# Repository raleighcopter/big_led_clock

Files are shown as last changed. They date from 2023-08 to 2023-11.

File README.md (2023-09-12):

BFC 1.0 (Big Filament Clock 1.0)

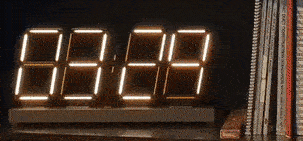
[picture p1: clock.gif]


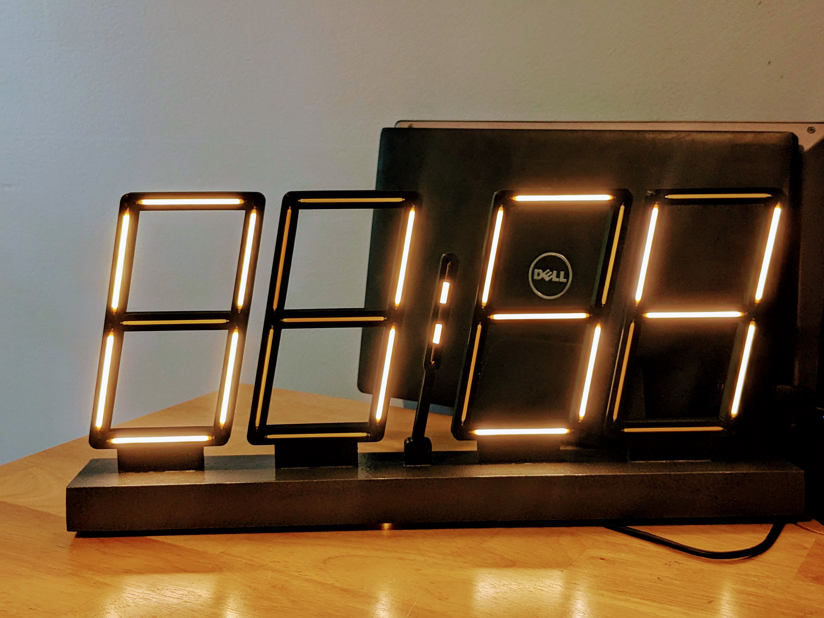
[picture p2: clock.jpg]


Some notes...

this clock is 17" x8" x 2.5" overall.

uses 68mm 3v filaments sourced from aliexpress. digits are about 6.5" tall. get the gps module and bme280 sensor for the optional transmitter there too.

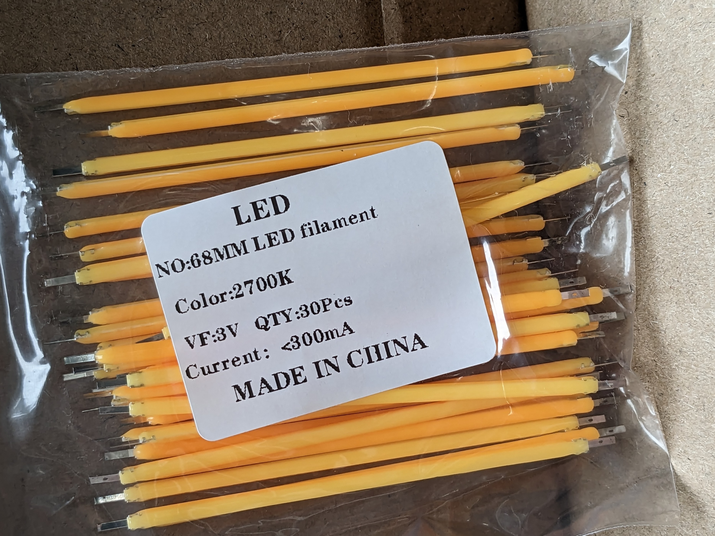
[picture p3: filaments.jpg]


the clock software now has the ability to blank leading zeros and the ability to display in 12 or 24 hour format through a few configuration settings.

the clock has the option to add a couple transistors (ss8550 with 1k base resistor) and configure the software to dim the entire display during night hours or without the addition of 2 transistors, to dim the colon and turn the digits off. You can optionally omit the buck converter but it does add some display brightness control, especially if you omit the ss8550 transistors which can dim the digits with a bit of code configuration changes.

Order extra LED filaments. They're brittle, fragile and you will break more than one. Sourced from AliExpress. the digits are wired common anode (the white wire).
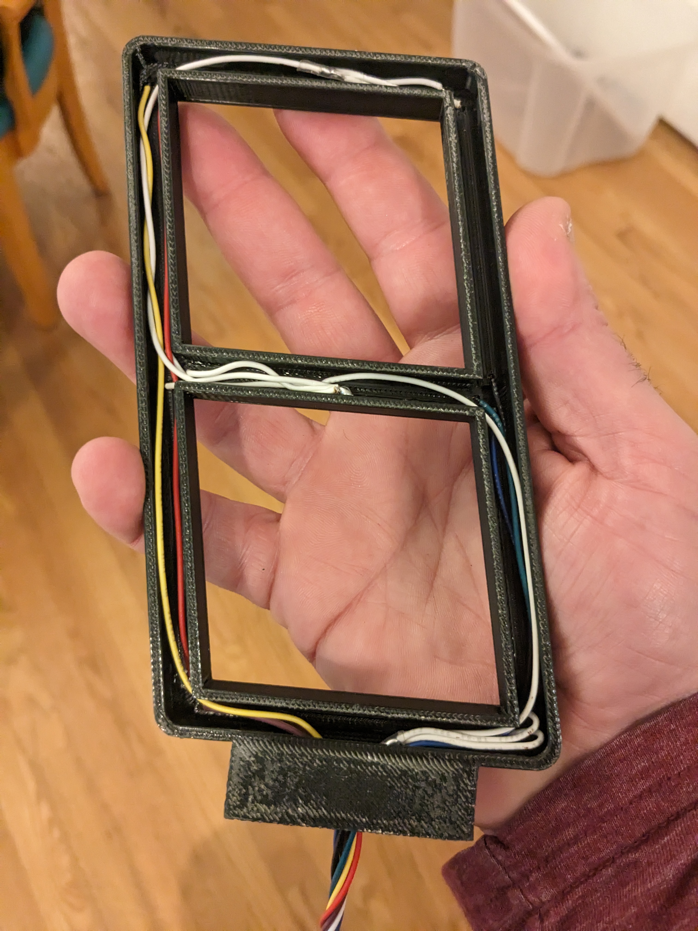
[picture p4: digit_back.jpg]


Here's a picture of the front.
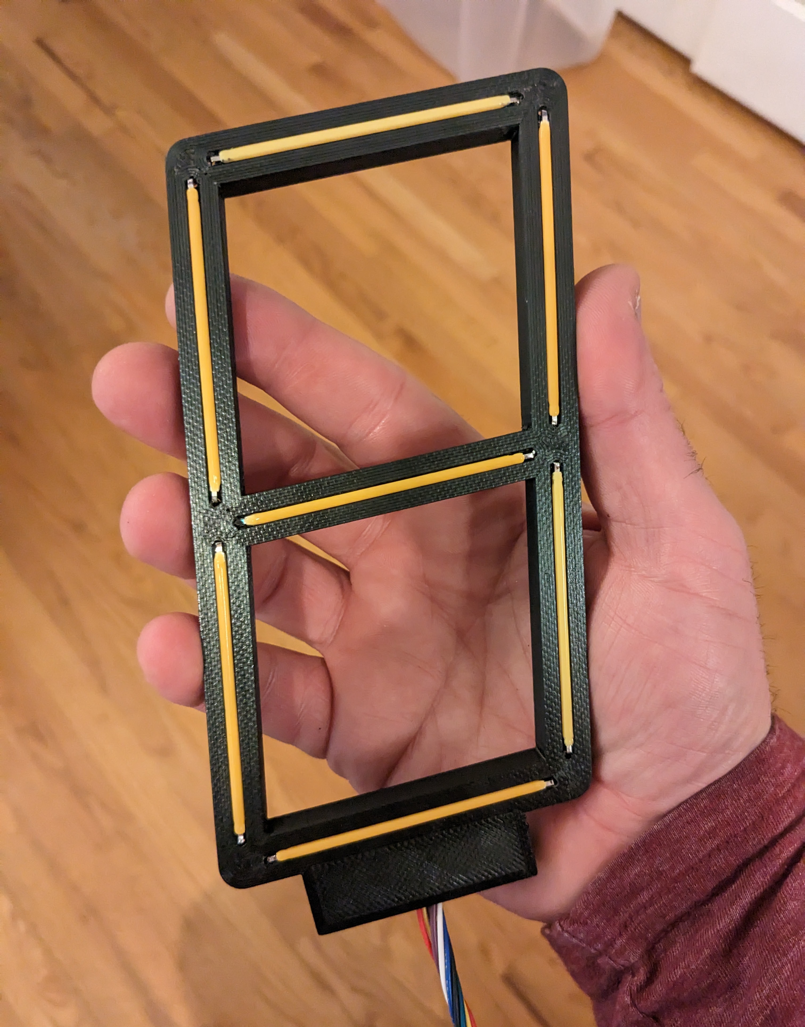
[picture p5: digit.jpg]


THE 433 MHZ receiver/transmitter with functionality is also working and an optional transmitter with bme280 (recommended) or si7021 temp/rh sensor can be used to wirelessly transmit weather data to the clock. you can build the clock with the receiver and build the transmitter at a later date and the clock will only display time unless a transmitter with matching transmitter code is detected.

The 3v converter can be omitted but you won't be able to set the brightness of the LEDs if you do, so play with the value of the series resistors for the LEDs if you omit the buck converter. You want at least 100 ohm series resistors, possibly higher.
  
You can omit the DST switch and just use the hour offset pot to adjust the hour for DST.

I used 1/4" poplar for the base and painted it with some left-over hammer tone grey paint i had on hand.

I used 3er perf board to build the circuit. It's available cheapest on eBay.

The GPS module is a neo6m module from AliExpress and it provides an accurate time source. more importantly, after a power outage, the clock will come back with the correct time without the need to set the clock and it doesn't require a battery backup, just a weak gps signal.

Drill the holes for the filament wires out to about 3/64" so the filaments don't break when installing them.they should be just big enough to get the wire and solder through but not too big or the filament won't stay in place. the LEDs are very fragile and you will break a few.

Use 1/8" black heat shrink to make the single filament in the colon look like a colon.

Wire the entire thing with 26 gage stranded. Get an assortment of colors to help stay organized. 8 colors or more is best.

here's a photo of the clock wiring.

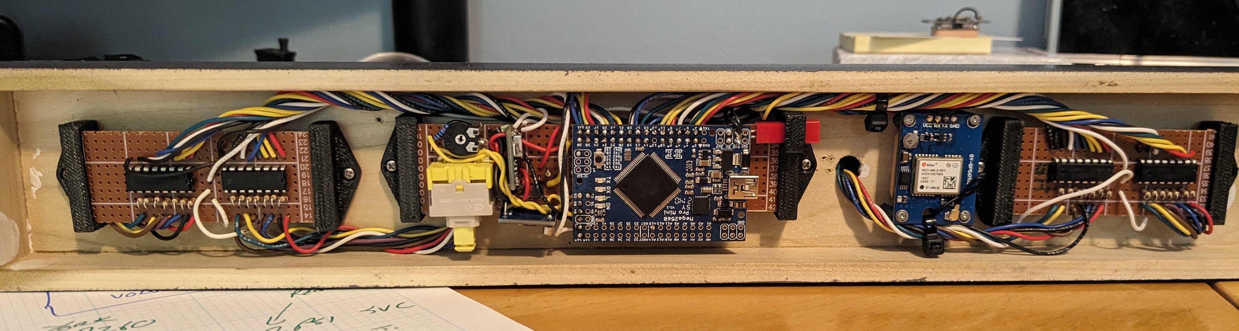
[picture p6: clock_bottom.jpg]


here's a photo of the transmitter built on a pro-mini with bme280 sensor and 433MHz transmitter. it can be built using the BME280 or the si7021 sensor. firmware for each is provided. i didn't do a schematic for the transmitter because its fairly trivial. the sensors are i2c and the transmitter pin is listed in the source code. the si7021 doesn't do well with relative humidity above 80% for extended periods which is daily around here so i use the BME280. 

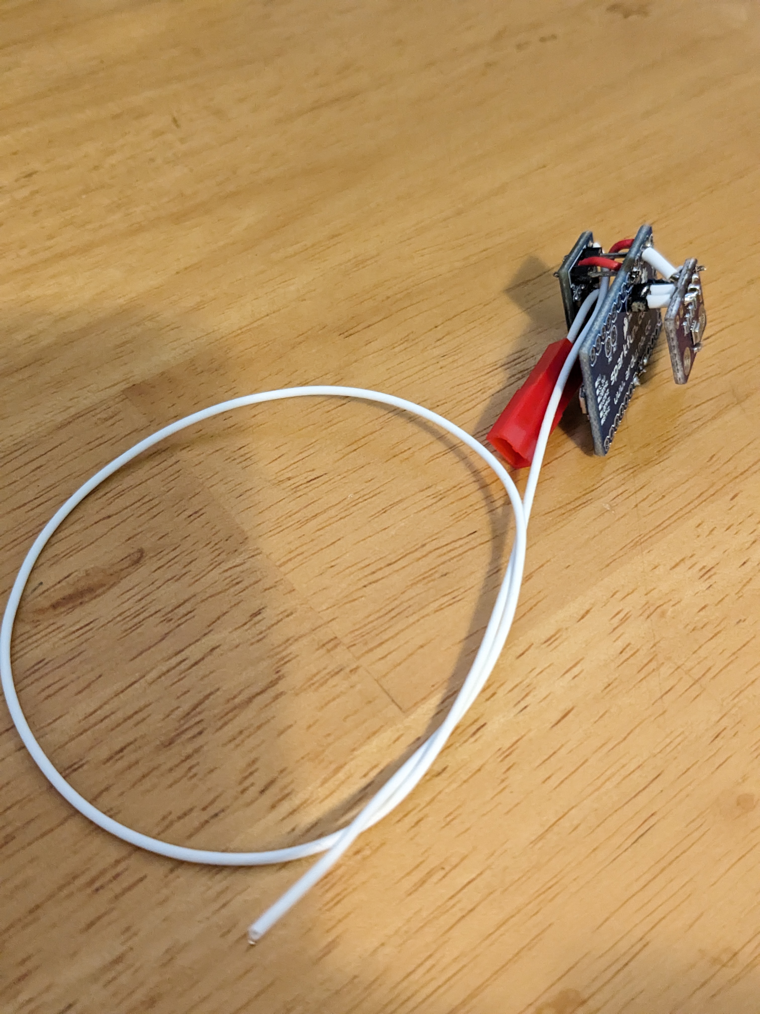
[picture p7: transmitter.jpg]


and the transmitter in the gill screen(top off).

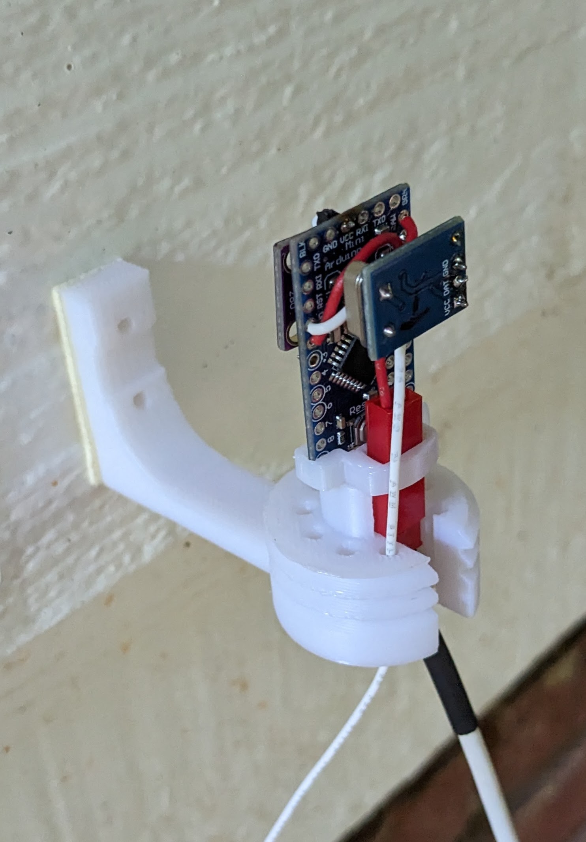
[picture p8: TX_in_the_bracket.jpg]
.

Contact me at d.a.taylor.pe@gmail.com

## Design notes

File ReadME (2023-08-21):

Big Clock

Some notes...

Order extra LED filaments. They're brittle, fragile and you will break more than one. Sourced from AliExpress.

THE 433 MHZ functionality is not incorporated yet.

The 3v converter can be omitted but you won't be able to set the brightness of the LEDs if you do so play with the value of the series resistors for the LEDs. You want at least 100 ohm series resistors, possibly higher.
  
You can omit the DST switch and just use the hour offset pot to adjust the hour for DST.

I used 1/4" poplar for the base and painted it with some hammer tone grey paint.

I used 3er perf board to build the circuit. It's available cheapest on eBay.

The GPS module is a neo6m module from AliExpress.

Drill the holes for the filament wires out to about 3/64" so the filaments don't break when installing them.they should be just big enough to get the wire and solder through but not too big or the filament won't stay in place.

Use heat shrink to make the single filament in the colon look like a colon.

Wire the entire thing with 22 gage stranded. Get an assortment of colors to help stay organized. 8 colors or more is best.

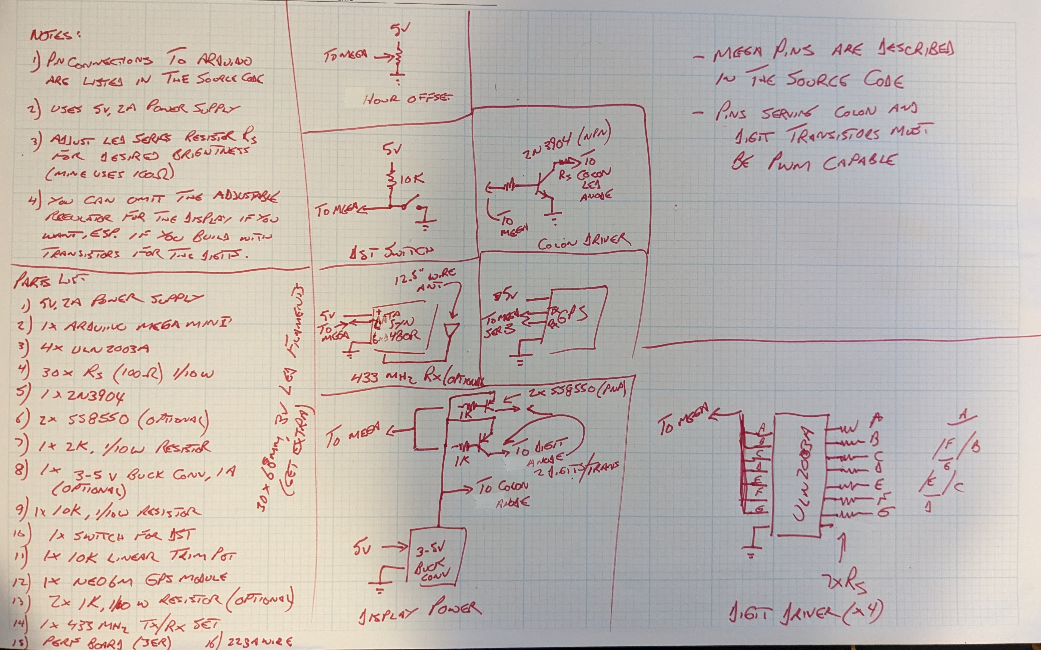
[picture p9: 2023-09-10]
clock_schematic.jpg

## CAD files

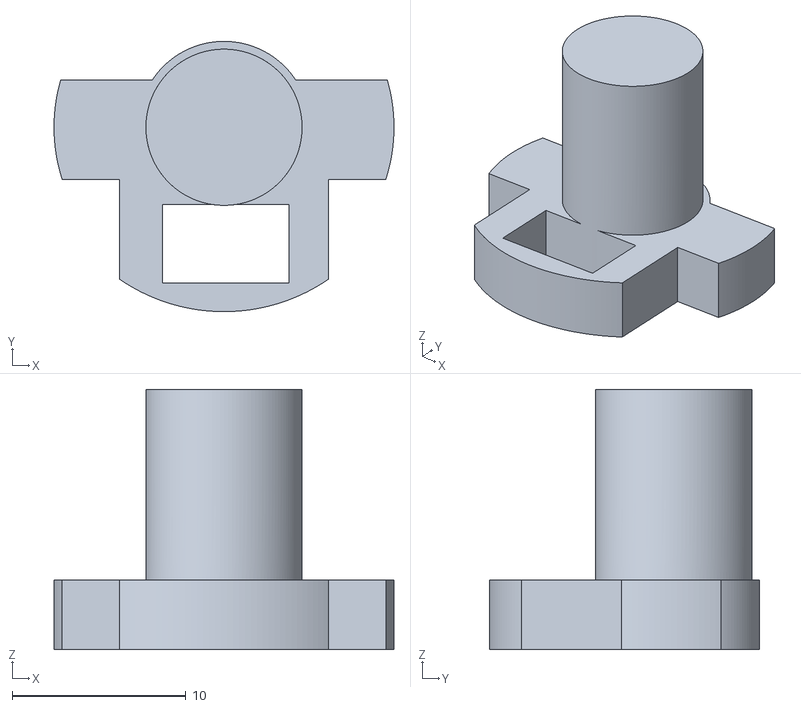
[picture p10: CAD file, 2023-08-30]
transmitter bracket.stl
19.6 x 15.6 x 15.0

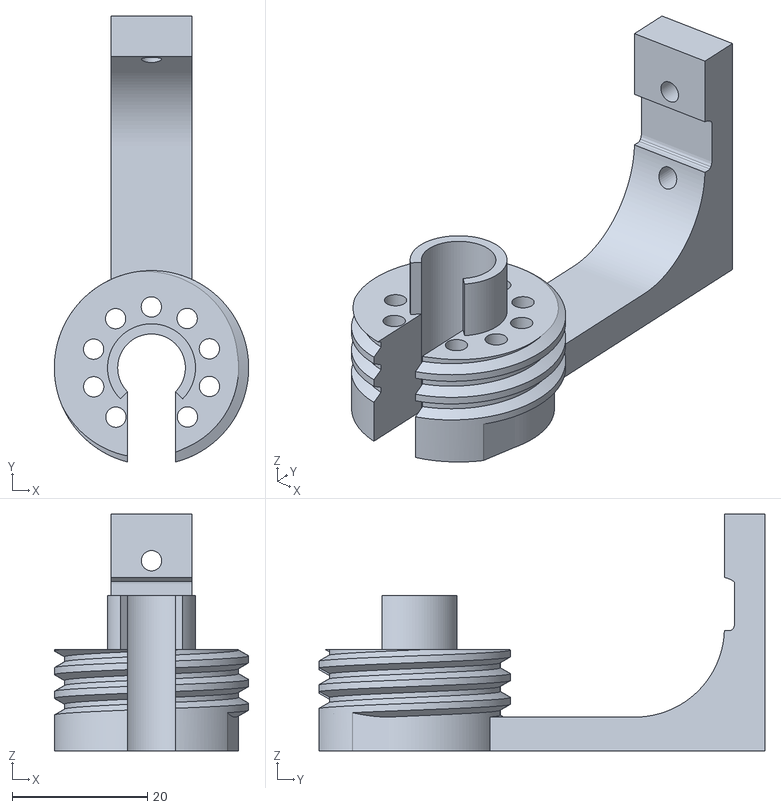
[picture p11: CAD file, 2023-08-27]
stevenson_base.stl
28.7 x 65.9 x 35.0

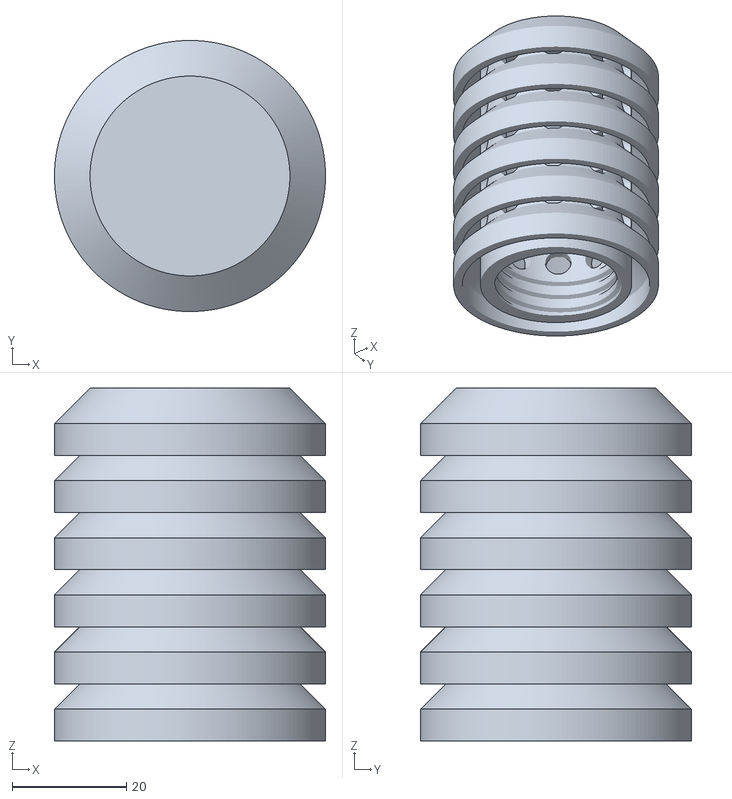
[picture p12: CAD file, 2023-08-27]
stevenson_cap.stl
47.5 x 47.5 x 61.8

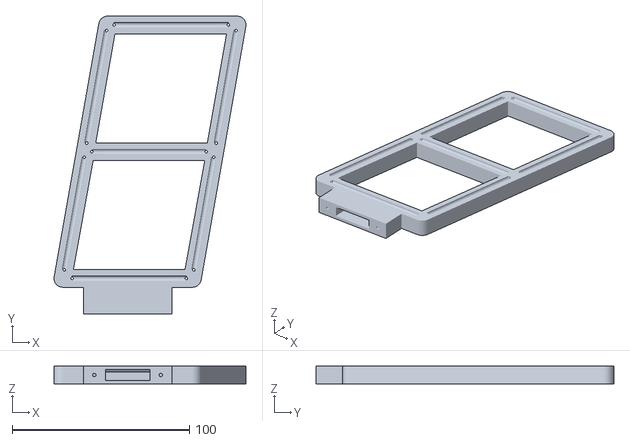
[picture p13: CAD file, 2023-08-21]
number.stl
108.4 x 168.1 x 10.0

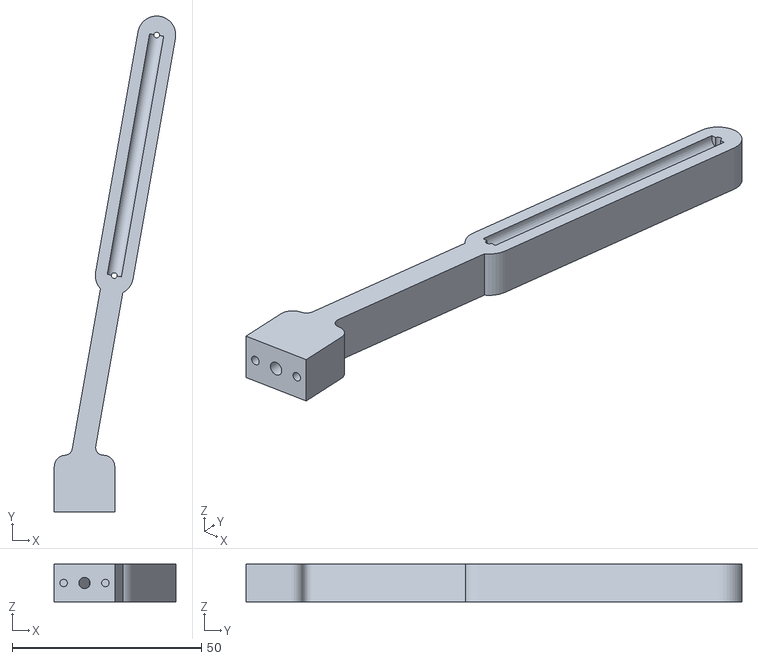
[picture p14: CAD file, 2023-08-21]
colon.stl
32.1 x 131.0 x 10.0

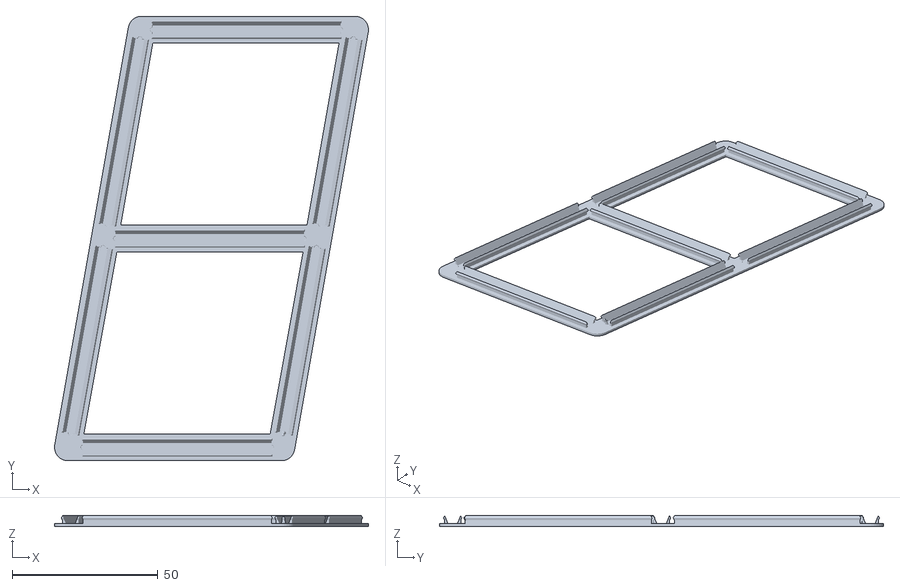
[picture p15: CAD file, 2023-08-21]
Back.stl
107.6 x 152.3 x 3.80

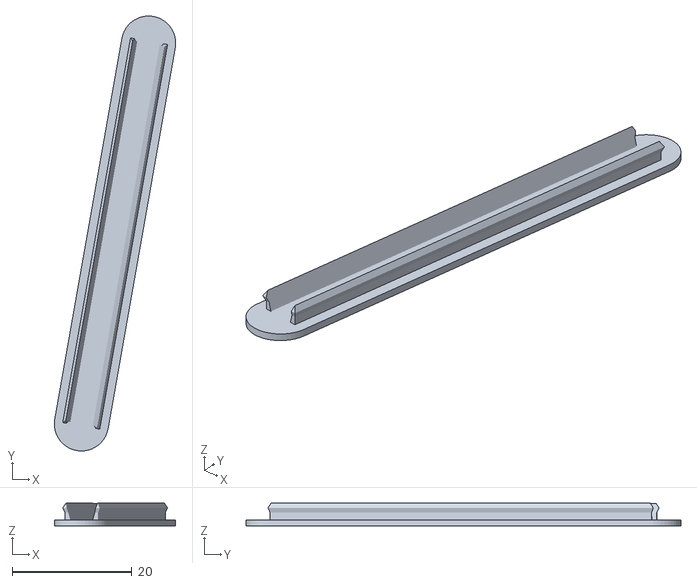
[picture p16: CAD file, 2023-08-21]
colon back.stl
20.3 x 72.6 x 3.80

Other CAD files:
clock digits.f3d
transmitter bracket.f3d

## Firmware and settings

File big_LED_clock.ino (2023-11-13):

/*


the segments of the digits are labeled as follows
         _____    
        /  A /   
       /F   /B  
      /____/     
     /  G /    
    /E   /C  
   /____/     
     D           

the gps is wired to serial3 (14,15)

*/


//make config changes in the area of code below

int leading_zero_blanking = 1; //set to 1 to enable
int format_12 = 1; //set to 1 to enable 12 hour time
int receiver_code = 152; //must match transmitter code
int dimmable_display = 1; //set to 1 if the display is wired with a PNP transistor (ss8550 with 1k base resistor) on the display power wire
int nite_off = 23; // dim display at this hour and after
int morning_on = 7; // dim display before this hour
int dim_level = 5; //amount to dim display (0-255)
int display_dim_pin = 44; //optional pwm pin for display digit dimming
int offset_pin = A15; //analog pin for hour offset pot
int dst_pin = 48; //the dst button pin
int RF_data_pin = 40; //the receiver data pin

//pins that the display segments are wired to are defined below

int hours_ten_a = 27;
int hours_ten_b = 28;
int hours_ten_c = 29;
int hours_ten_d = 30;
int hours_ten_e = 31;
int hours_ten_f = 46;
int hours_ten_g = 47;

int hours_one_a = 20;
int hours_one_b = 21;
int hours_one_c = 22;
int hours_one_d = 23;
int hours_one_e = 24;
int hours_one_f = 25;
int hours_one_g = 26;

int minutes_ten_a = 9;
int minutes_ten_b = 10;
int minutes_ten_c = 11;
int minutes_ten_d = 16;
int minutes_ten_e = 17;
int minutes_ten_f = 18;
int minutes_ten_g = 19;

int minutes_one_a = 2;
int minutes_one_b = 7;
int minutes_one_c = 6;
int minutes_one_d = 5;
int minutes_one_e = 4;
int minutes_one_f = 3;
int minutes_one_g = 8;

int colon = 13; // the pin that the colon is wired to. must be a PWM capable pin

// make config changes above this line only

#include <TinyGPS++.h>  //TinyGPSPlus library
#include <RH_ASK.h>     //Radiohead library

RH_ASK driver(2000, RF_data_pin, 0, 0);

static const uint32_t GPSBaud = 9600;

int on = 1;
int off = 0;
int dot_count;
int colon_val;
int hi_dot = 255;

int hour_offset;

int a;
int b;
int c;
int d;
int e;
int f;
int g;

int hours = 0;
int minutes = 0;
int seconds = 0;
int hours_ten = 0;
int hours_one = 0;
int minutes_ten = 0;
int minutes_one = 0;

int weather_time = 0;
int weather_valid = 0;
int Temp;
int RH;

TinyGPSPlus gps;

void setup()
{

#ifdef RH_HAVE_SERIAL
    Serial.begin(9600);	  // Debugging only
#endif
    if (!driver.init())
#ifdef RH_HAVE_SERIAL
         Serial.println("init failed");
#else
         Serial.println("init success");	;
#endif

  Serial3.begin(GPSBaud);

  pinMode(hours_ten_a, OUTPUT);
  pinMode(hours_ten_b, OUTPUT);
  pinMode(hours_ten_c, OUTPUT);
  pinMode(hours_ten_d, OUTPUT);
  pinMode(hours_ten_e, OUTPUT);
  pinMode(hours_ten_f, OUTPUT);
  pinMode(hours_ten_g, OUTPUT);
  pinMode(hours_one_a, OUTPUT);
  pinMode(hours_one_b, OUTPUT);
  pinMode(hours_one_c, OUTPUT);
  pinMode(hours_one_d, OUTPUT);
  pinMode(hours_one_e, OUTPUT);
  pinMode(hours_one_f, OUTPUT);
  pinMode(hours_one_g, OUTPUT);
  pinMode(minutes_ten_a, OUTPUT);
  pinMode(minutes_ten_b, OUTPUT);
  pinMode(minutes_ten_c, OUTPUT);
  pinMode(minutes_ten_d, OUTPUT);
  pinMode(minutes_ten_e, OUTPUT);
  pinMode(minutes_ten_f, OUTPUT); 
  pinMode(minutes_ten_g, OUTPUT);
  pinMode(minutes_one_a, OUTPUT);
  pinMode(minutes_one_b, OUTPUT);
  pinMode(minutes_one_c, OUTPUT);
  pinMode(minutes_one_d, OUTPUT);
  pinMode(minutes_one_e, OUTPUT);
  pinMode(minutes_one_f, OUTPUT);
  pinMode(minutes_one_g, OUTPUT);
  pinMode(dst_pin, INPUT); 
}

void loop()
{
//get weather data if available
  int data[3] = {0};
      uint8_t buflen = sizeof(data);
    if (driver.recv((uint8_t*)data, &buflen));
   {
  if (data[0] == receiver_code) {  //throw away bad data
    RH = data[1];
    Temp = data[2];
    weather_time =  (60 * minutes) + seconds; //record time of weather aquisition
    weather_valid = 1; //mark weather as valid
  }
}


  // This sketch displays information every time a new NMEA sentence is correctly encoded.
  while (Serial3.available() > 0)
    if (gps.encode(Serial3.read()))
      displayInfo();

  if (millis() > 5000 && gps.charsProcessed() < 10)
  {
    Serial.println(F("No GPS detected: check wiring."));
    while(true);
  }
  hour_offset = map(analogRead(offset_pin), 0, 1023, 23, 0) + digitalRead(dst_pin);

}

void displayInfo()
{
  if (gps.time.isValid())
// store values in working variables 
  {
  hours = gps.time.hour();
  minutes = gps.time.minute();
  seconds = gps.time.second();

  hours = hours + hour_offset;



//invalidate weather data that's too old
if ((60 * minutes + seconds) - weather_time >= 60) {
  weather_valid = 0;
}

//adjust to 24 hour local time
  if (hours > 24) hours = hours - 24;
  if (hours < 1) hours = hours + 24;

// dim during off hours
    if ((hours >= nite_off) or (hours < morning_on)) {
      hi_dot = dim_level; //dim the colon
      if (dimmable_display == 1) { //dim the digits if they're dimmable
        analogWrite(display_dim_pin, (255 - dim_level));
      }
      else {
        on = 0; //digits not dimmable so turn them off
      }
    } else {
      hi_dot = 255;
      on = 1;
      analogWrite(display_dim_pin, 0);
    }

//ramp up during morning_on hour


//ramp down during nite_off hour


//convert to 12 hour format if format_12 = 1  
  if (format_12 == 1) {
    if (hours > 12) hours = hours - 12;
    if (hours < 1) hours = hours + 12;
    }
   }


//determine if we should display time or temp
if ((weather_valid == 1) and seconds % 10 >= 8) {
//display RH
    colon_val = off;
    hours_ten = (RH/10);
    hours_one = (RH - (10 * hours_ten));
    minutes_ten = 11;
    minutes_one = 12;
}

if ((weather_valid == 1) and (seconds % 10 >= 6 and seconds %10 < 8) ) {
  colon_val = off;
//display temp
  if ((Temp < 0) and (Temp >= -9)) {
    Temp = abs(Temp);
    hours_ten = 10;  // minus
    hours_one = Temp;
    minutes_ten = 10; //degrees
    minutes_one = 11; //F
  } else if (Temp <= -10) {
    Temp = abs(Temp);
    hours_ten = 10; //minus
    hours_one = (Temp/10);
    minutes_ten = (Temp - (10 * hours_one));
    minutes_one = 10; //degrees
  } else if ((Temp >= 0) and (Temp <100)) {
    hours_ten = (Temp/10);
    hours_one = (Temp - (10 * hours_ten));
    minutes_ten = 10; //degrees
    minutes_one = 11; //F
  } else if (Temp >= 100) {
    hours_ten = 1;
    Temp = Temp - 100;
    hours_one = (Temp/10);
    minutes_ten = (Temp - (10 * hours_one));
    minutes_one = 10; //degrees     
    }
}

if ((seconds % 10 <= 5) or (weather_valid == 0)) {
//display time
// calculate values for separate digits to display time
  hours_ten = (hours/10);
  hours_one = (hours - (10 * hours_ten));
  minutes_ten = (minutes/10);
  minutes_one = (minutes - (10 * minutes_ten));

//do colon stuff....
  dot_count = seconds % 2;

  switch(dot_count)
  {
    case 0: colon_val = hi_dot; break;
    case 1: colon_val = off; break; 
  }
}


//do display stuff
// write colon

analogWrite(colon, colon_val);

// set the display segments

switch(hours_ten)
{
  case 0: if (leading_zero_blanking = 0) {
    a=on;b=on;c=on;d=on;e=on;f=on;g=off;
    } else { 
    a=off;b=off;c=off;d=off;e=off;f=off;g=off;
    }
    break;
  case 1: a=off;b=on;c=on;d=off;e=off;f=off;g=off;break;
  case 2: a=on;b=on;c=off;d=on;e=on;f=off;g=on;break;
  case 3: a=on;b=on;c=on;d=on;e=off;f=off;g=on;break;
  case 4: a=off;b=on;c=on;d=off;e=off;f=on;g=on;break;
  case 5: a=on;b=off;c=on;d=on;e=off;f=on;g=on;break;
  case 6: a=on;b=off;c=on;d=on;e=on;f=on;g=on;break;
  case 7: a=on;b=on;c=on;d=off;e=off;f=off;g=off;break;
  case 8: a=on;b=on;c=on;d=on;e=on;f=on;g=on;break;
  case 9: a=on;b=on;c=on;d=off;e=off;f=on;g=on;break;
  case 10: a=off;b=off;c=off;d=off;e=off;f=off;g=on;break; // - symbol    
}
// write hours_ten digit display pins
  
digitalWrite(hours_ten_a, a);
digitalWrite(hours_ten_b, b);
digitalWrite(hours_ten_c, c);
digitalWrite(hours_ten_d, d);
digitalWrite(hours_ten_e, e);
digitalWrite(hours_ten_f, f);
digitalWrite(hours_ten_g, g);

switch(hours_one)
{
  case 0: a=on;b=on;c=on;d=on;e=on;f=on;g=off;break;
  case 1: a=off;b=on;c=on;d=off;e=off;f=off;g=off;break;
  case 2: a=on;b=on;c=off;d=on;e=on;f=off;g=on;break;
  case 3: a=on;b=on;c=on;d=on;e=off;f=off;g=on;break;
  case 4: a=off;b=on;c=on;d=off;e=off;f=on;g=on;break;
  case 5: a=on;b=off;c=on;d=on;e=off;f=on;g=on;break;
  case 6: a=on;b=off;c=on;d=on;e=on;f=on;g=on;break;
  case 7: a=on;b=on;c=on;d=off;e=off;f=off;g=off;break;
  case 8: a=on;b=on;c=on;d=on;e=on;f=on;g=on;break;
  case 9: a=on;b=on;c=on;d=off;e=off;f=on;g=on;break;           
}
// write hours_one digit display pins
  
digitalWrite(hours_one_a, a);
digitalWrite(hours_one_b, b);
digitalWrite(hours_one_c, c);
digitalWrite(hours_one_d, d);
digitalWrite(hours_one_e, e);
digitalWrite(hours_one_f, f);
digitalWrite(hours_one_g, g);

switch(minutes_ten)
{
  case 0: a=on;b=on;c=on;d=on;e=on;f=on;g=off;break;
  case 1: a=off;b=on;c=on;d=off;e=off;f=off;g=off;break;
  case 2: a=on;b=on;c=off;d=on;e=on;f=off;g=on;break;
  case 3: a=on;b=on;c=on;d=on;e=off;f=off;g=on;break;
  case 4: a=off;b=on;c=on;d=off;e=off;f=on;g=on;break;
  case 5: a=on;b=off;c=on;d=on;e=off;f=on;g=on;break;
  case 6: a=on;b=off;c=on;d=on;e=on;f=on;g=on;break;
  case 7: a=on;b=on;c=on;d=off;e=off;f=off;g=off;break;
  case 8: a=on;b=on;c=on;d=on;e=on;f=on;g=on;break;
  case 9: a=on;b=on;c=on;d=off;e=off;f=on;g=on;break;
  case 10: a=on;b=on;c=off;d=off;e=off;f=on;g=on;break; // degree symbol
  case 11: a=off;b=off;c=off;d=off;e=on;f=off;g=on;break; //r      
}
// write minutes_ten digit display pins
  
digitalWrite(minutes_ten_a, a);
digitalWrite(minutes_ten_b, b);
digitalWrite(minutes_ten_c, c);
digitalWrite(minutes_ten_d, d);
digitalWrite(minutes_ten_e, e);
digitalWrite(minutes_ten_f, f);
digitalWrite(minutes_ten_g, g);

switch(minutes_one)
{
  case 0: a=on;b=on;c=on;d=on;e=on;f=on;g=off;break;
  case 1: a=off;b=on;c=on;d=off;e=off;f=off;g=off;break;
  case 2: a=on;b=on;c=off;d=on;e=on;f=off;g=on;break;
  case 3: a=on;b=on;c=on;d=on;e=off;f=off;g=on;break;
  case 4: a=off;b=on;c=on;d=off;e=off;f=on;g=on;break;
  case 5: a=on;b=off;c=on;d=on;e=off;f=on;g=on;break;
  case 6: a=on;b=off;c=on;d=on;e=on;f=on;g=on;break;
  case 7: a=on;b=on;c=on;d=off;e=off;f=off;g=off;break;
  case 8: a=on;b=on;c=on;d=on;e=on;f=on;g=on;break;
  case 9: a=on;b=on;c=on;d=off;e=off;f=on;g=on;break;
  case 10: a=on;b=on;c=off;d=off;e=off;f=on;g=on;break; // degree symbol
  case 11: a=on;b=off;c=off;d=off;e=on;f=on;g=on;break; // F
  case 12: a=off;b=off;c=on;d=off;e=on;f=on;g=on;break; //h           
}
// write minutes_one digit display pins
  
digitalWrite(minutes_one_a, a);
digitalWrite(minutes_one_b, b);
digitalWrite(minutes_one_c, c);
digitalWrite(minutes_one_d, d);
digitalWrite(minutes_one_e, e);
digitalWrite(minutes_one_f, f);
digitalWrite(minutes_one_g, g);
  
}

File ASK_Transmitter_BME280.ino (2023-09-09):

//transmits temp and relative humidity data. 
//build on arduino nano or pro mini.
//uses an bme280 sensor and cheap 433 MHz transmitter.
//the transmitter connects to D2. 
//sends a new set of data about every 3 seconds.

#include <RH_ASK.h>
#ifdef RH_HAVE_HARDWARE_SPI
#include <SPI.h> 
#include <Wire.h>
#include <Adafruit_Sensor.h>
#include <Adafruit_BME280.h>
#endif
Adafruit_BME280 bme; // I2C

RH_ASK driver(2000, 0, 2, 0);

int transmitter_code = 152; // must match receiver code
void setup()
{
unsigned status;

status = bme.begin(0x76);

#ifdef RH_HAVE_SERIAL
    Serial.begin(9600);	  // Debugging only
#endif
    if (!driver.init())
#ifdef RH_HAVE_SERIAL
         Serial.println("init failed");
#else
         Serial.println("init success");	;
#endif

}
void loop() {
//  Serial.print("Humidity:    ");
//  Serial.print(bme.readHumidity(), 2);
//  Serial.print("\tTe0mperature: ");
//  Serial.println(bme.readTemperature(), 2);
int data[3];
data[0] = transmitter_code;
data[1] = int (bme.readHumidity()),2;
data[2] = int (1.8 * (bme.readTemperature()) +32),2;
    driver.send((uint8_t*)data,6);
    driver.waitPacketSent();
  //  Serial.print("Sent: ");Serial.print(data[0]);Serial.println(data[1]);
    delay(3000);
}

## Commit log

2023-08-26 Update big_LED_clock.ino
    added weather display and changed receiver to pin 40
2023-08-27 Add files via upload
    transmitter case
    [stevenson_base.stl, stevenson_cap.stl]
2023-08-27 Update big_LED_clock.ino
    fixed temp over 100 display
    [big_LED_clock.ino]
2023-08-28 Update ask_transmitter.ino
    added correction factors for temp and rh sensor
    [ask_transmitter.ino]
2023-08-28 Update ask_transmitter.ino
    i'm not sure i like this si7021 sensor. will try bme280 tomorrow
2023-08-28 Update ask_transmitter.ino
    i need to stop screwing with the sensor calibration. my sensor is all over the place.
2023-08-29 Add files via upload
    arduino pro mini with bme280 sensor and 433 mhz transmitter module
2023-08-29 Add files via upload
    the clock wiring
2023-08-30 Add files via upload
    transmitter bracket
    [transmitter bracket.f3d, transmitter bracket.stl]
2023-09-09 added large digit dimming with ss8550 transistors.
    base wired to display_dim_pin through a 1k resistor.
    set dimmable_display to 1 to enable.
2023-09-09 Add files via upload
    added digit transistors to schematic
